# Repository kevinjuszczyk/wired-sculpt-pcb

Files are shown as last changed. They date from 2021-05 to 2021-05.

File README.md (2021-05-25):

# Design Files for Wired Sculpt Conversion Board
Modified for fabrication and assembly by JLCPCB.  
Components in the BOM with an LCSC number can be placed by JLCPCB.  
Remaining components can be ordered from Digikey and hand assembled.  
This design includes support for lighting the green LED and reading the media/Fn switch.

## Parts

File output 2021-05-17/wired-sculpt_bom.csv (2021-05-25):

Comment | Designator | Footprint | Desc | LCSC | Mfr | MfrPN | Link
10u | C2 | Capacitor_SMD:C_0603_1608Metric | 10uF ±10% 10V X5R | C19702 | Samsung Electro-Mechanics | CL10A106KP8NNNC
12p | C3,C4 | Capacitor_SMD:C_0603_1608Metric | 12pF ±5% 50V C0G 0603 | C38523 | Samsung Electro-Mechanics | CL10C120JB8NNNC
1u | C5 | Capacitor_SMD:C_0603_1608Metric | 1uF ±10% 50V X5R 0603 | C15849 | Samsung Electro-Mechanics | CL10A105KB8NNNC
100n | C6,C7,C8,C1 | Capacitor_SMD:C_0603_1608Metric | 100nF ±10% 50V X7R 0603 | C14663 | YAGEO | CC0603KRX7R9BB104
22u | C9,C10,C11 | Capacitor_SMD:C_0603_1608Metric | 22uF ±20% 6.3V X5R 0603 | C59461 | Samsung Electro-Mechanics | CL10A226MQ8NRNC
BAV99 | D1 | Package_TO_SOT_SMD:SOT-23 | Switching Diode 100V 125mA 1.25V @ 150mA 4ns SOT-23(SOT-23-3) | C2500 | Nexperia | BAV99,215
Red | D2 | LED_SMD:LED_0603_1608Metric_Castellated | Light Emitting Diodes (LED) Red 520~625nm 90~100mcd@20mA Top View 0603 | C2286 | Hubei KENTO Elec | KT-0603R
MountingHoleNorth | H1 | MountingHole:MountingHole_2.2mm_M2
MountingHoleSouth | H2 | MountingHole:MountingHole_2.2mm_M2
AlignmentHole | H3 | MountingHole:MountingHole_2.7mm
10103594-0001LF | J1 | Connector_USB:USB_Micro-B_Molex-105017-0001 | CONN RCPT USB2.0 MICRO B SMD R/A |  | Molex | 1050170001 | https://www.digikey.com/en/products/detail/molex/1050170001/2350885
AVR-ISP-6 - NOT FITTED | J2 | Connector_IDC:IDC-Header_2x03_P2.54mm_Horizontal
FFC3B07-30-T | J3 | Connector_FFC-FPC:TE_3-84952-0_1x30-1MP_P1.0mm_Horizontal | CONN FPC BOTTOM 30POS 1.00MM R/A |  | TE Connectivity AMP Connectors | 3-84952-0 | https://www.digikey.com/en/products/detail/te-connectivity-amp-connectors/3-84952-0/2180597
100 | R1 | Resistor_SMD:R_0603_1608Metric | 100Ω ±1% 1/10W ±200ppm/°C 0603 | C22775 | UNI-ROYAL(Uniroyal Elec) | 0603WAF1000T5E
22 | R2,R3 | Resistor_SMD:R_0402_1005Metric | 22Ω ±1% 1/16W ±200ppm/℃ 0402 | C25092 | UNI-ROYAL(Uniroyal Elec) | 0402WGF220JTCE
470k | R4 | Resistor_SMD:R_0603_1608Metric | 470kΩ ±1% 0.1W ±100ppm/℃ 0603 | C23178 | UNI-ROYAL(Uniroyal Elec) | 0603WAF4703T5E
680 | R5,R6 | Resistor_SMD:R_0603_1608Metric | 680Ω ±1% 0.1W ±100ppm/℃ 0603 | C23228 | UNI-ROYAL(Uniroyal Elec) | 0603WAF6800T5E
MJTP1117 | SW1 | kmj_custom:SW_Tactile_SPST_Angled_MJTP1117 | SWITCH TACTILE SPST-NO 0.05A 12V |  | APEM Inc. | MJTP1117 | https://www.digikey.com/en/products/detail/apem-inc/MJTP1117/1795496
SRV05-4-P-T7 | U1 | Package_TO_SOT_SMD:SOT-23-6 | TVS SOT-23-6 | C85364 | ProTek Devices | SRV05-4-P-T7
AT90USB1286-AU | U2 | Package_QFP:TQFP-64_14x14mm_P0.8mm | TQFP-64 MCU | C619147 | Microchip Tech | AT90USB1286-AU
16M | Y1 | Crystal:Crystal_SMD_3225-4Pin_3.2x2.5mm | SMD Crystal Resonators 16MHz ±10ppm SMD-3225_4P | C13738 | Yangxing Tech | X322516MLB4SI

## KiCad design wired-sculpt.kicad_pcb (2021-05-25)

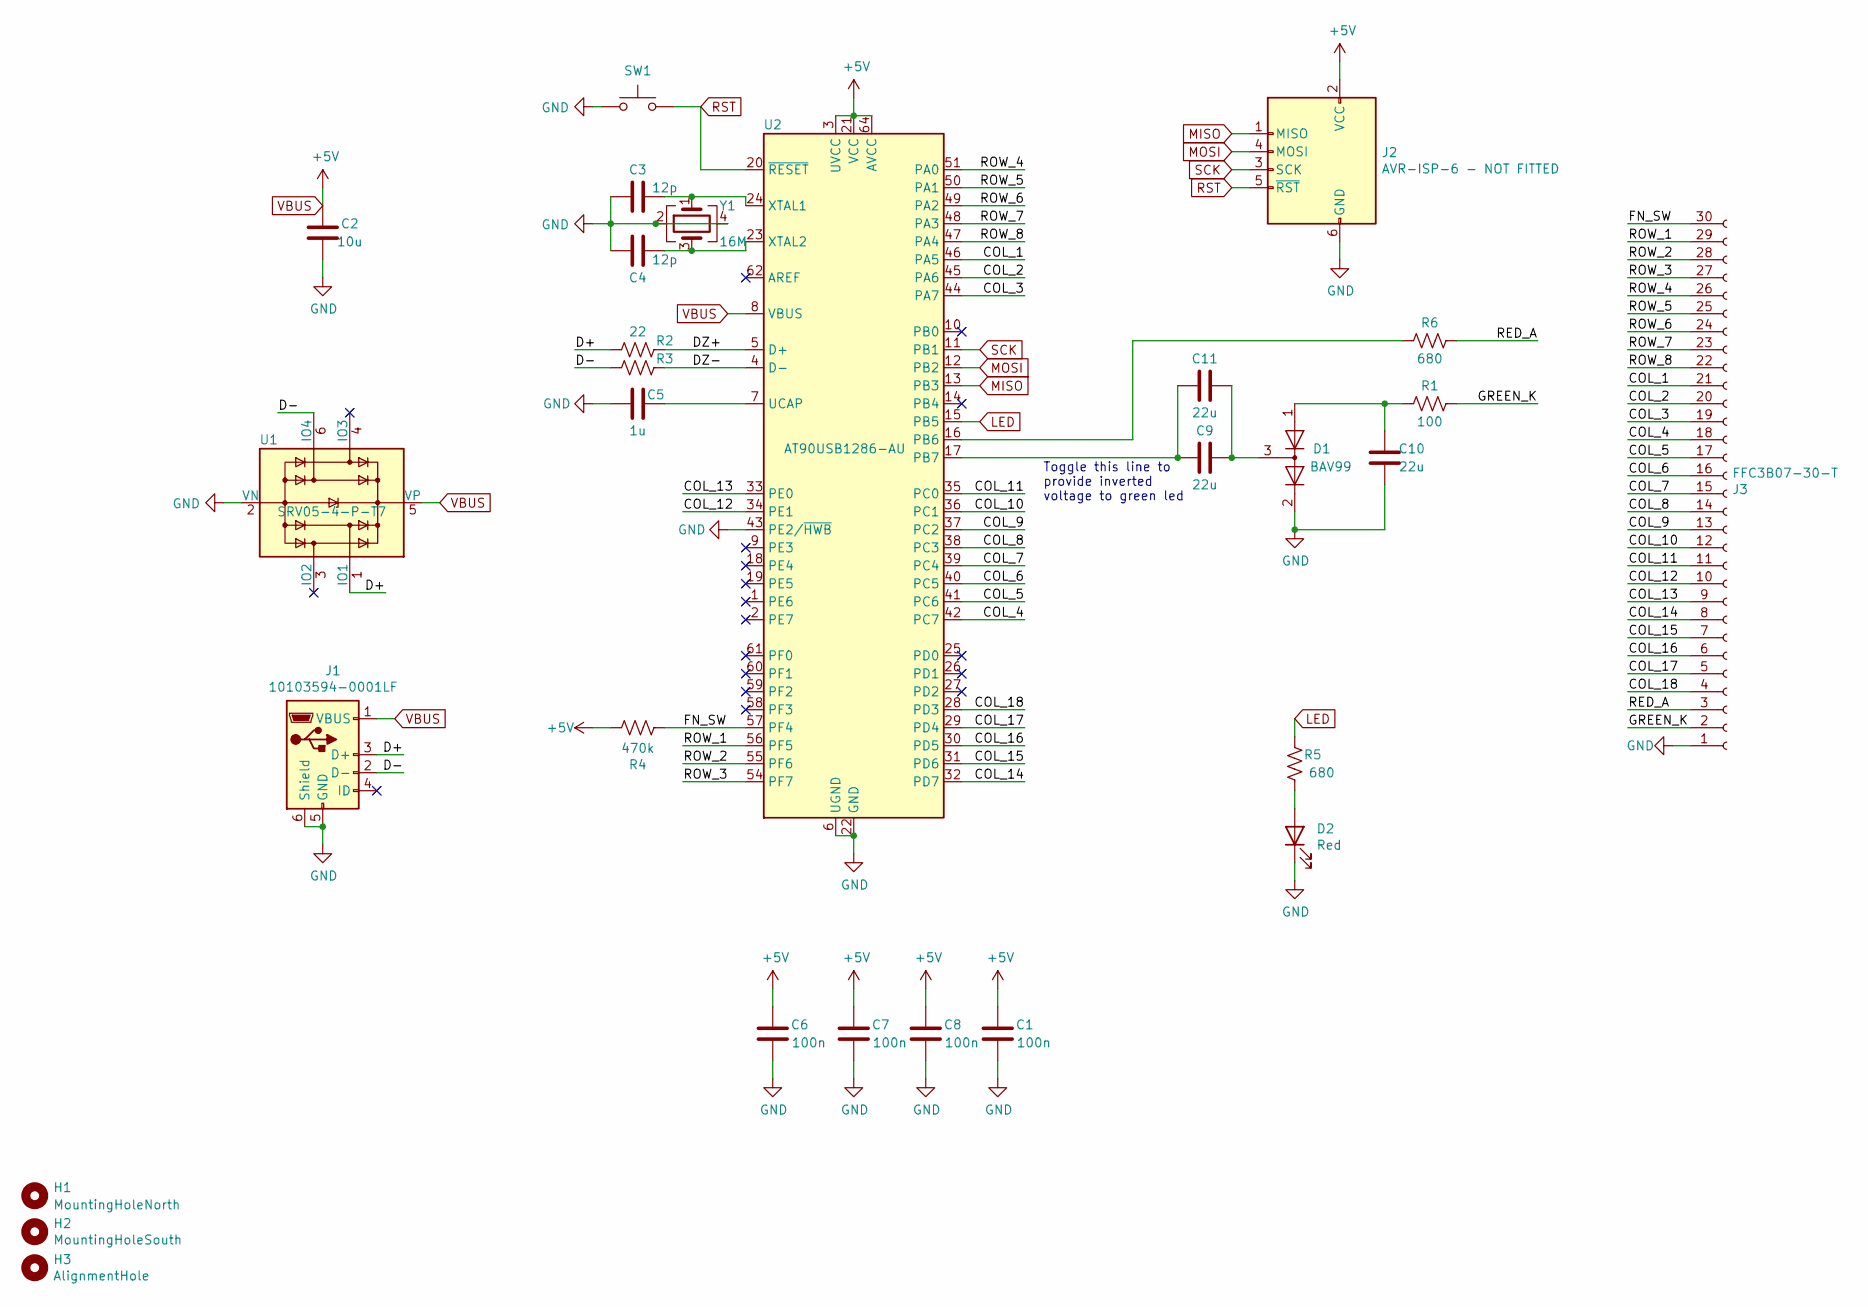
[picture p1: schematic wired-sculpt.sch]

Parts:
C1, C6, C7, C8: 100n; C_0603_1608Metric; Mfr_part CC0603KRX7R9BB104; LCSC C14663
C2: 10u; C_0603_1608Metric; Mfr_part CL10A106KP8NNNC; LCSC C19702
C3, C4: 12p; C_0603_1608Metric; Mfr_part CL10C120JB8NNNC; LCSC C38523
C5: 1u; C_0603_1608Metric; Mfr_part CL10A105KB8NNNC; LCSC C15849
C9, C10, C11: 22u; C_0603_1608Metric; Mfr_part CL10A226MQ8NRNC; LCSC C59461
D1: BAV99; SOT-23; Mfr_part BAV99,215; LCSC C2500
D2: Red; LED_0603_1608Metric_Castellated; Mfr_part KT-0603R; LCSC C2286
H1: MountingHoleNorth; MountingHole_2.2mm_M2
H2: MountingHoleSouth; MountingHole_2.2mm_M2
H3: AlignmentHole; MountingHole_2.7mm
J1: 10103594-0001LF; USB_Micro-B_Molex-105017-0001
J2: AVR-ISP-6 - NOT FITTED; IDC-Header_2x03_P2.54mm_Horizontal
J3: FFC3B07-30-T; TE_3-84952-0_1x30-1MP_P1.0mm_Horizontal
R1: 100; R_0603_1608Metric; Mfr_part 0603WAF1000T5E; LCSC C22775
R2, R3: 22; R_0402_1005Metric; Mfr_part 0402WGF220JTCE; LCSC C25092
R4: 470k; R_0603_1608Metric; Mfr_part 0603WAF4703T5E; LCSC C23178
R5, R6: 680; R_0603_1608Metric; Mfr_part 0603WAF6800T5E; LCSC C23228
SW1: MJTP1117; SW_Tactile_SPST_Angled_MJTP1117; Mfr_part MJTP1117
U1: SRV05-4-P-T7; SOT-23-6; Mfr_part SRV05-4-P-T7; LCSC C85364
U2: AT90USB1286-AU; TQFP-64_14x14mm_P0.8mm; Mfr_part AT90USB1286-AU; LCSC C619147
Y1: 16M; Crystal_SMD_3225-4Pin_3.2x2.5mm; Mfr_part X322516MLB4SI; LCSC C13738

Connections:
/COL_1: J3.21, U2.46 (PA5)
/COL_2: J3.20, U2.45 (PA6)
/COL_3: J3.19, U2.44 (PA7)
/COL_4: J3.18, U2.42 (PC7)
/COL_5: J3.17, U2.41 (PC6)
/COL_6: J3.16, U2.40 (PC5)
/COL_7: J3.15, U2.39 (PC4)
/COL_8: J3.14, U2.38 (PC3)
/COL_9: J3.13, U2.37 (PC2)
/COL_10: J3.12, U2.36 (PC1)
/COL_11: J3.11, U2.35 (PC0)
/COL_12: J3.10, U2.34 (PE1)
/COL_13: J3.9, U2.33 (PE0)
/COL_14: J3.8, U2.32 (PD7)
/COL_15: J3.7, U2.31 (PD6)
/COL_16: J3.6, U2.30 (PD5)
/COL_17: J3.5, U2.29 (PD4)
/COL_18: J3.4, U2.28 (PD3)
/D+: J1.3 (D+), R2.2, U1.1 (IO1)
/D-: J1.2 (D-), R3.2, U1.6 (IO4)
/DZ+: R2.1, U2.5 (D+)
/DZ-: R3.1, U2.4 (D-)
/FN_SW: J3.30, R4.2, U2.57 (PF4)
/GREEN_K: J3.2, R1.1
/RED_A: J3.3, R6.1
/ROW_1: J3.29, U2.56 (PF5)
/ROW_2: J3.28, U2.55 (PF6)
/ROW_3: J3.27, U2.54 (PF7)
/ROW_4: J3.26, U2.51 (PA0)
/ROW_5: J3.25, U2.50 (PA1)
/ROW_6: J3.24, U2.49 (PA2)
/ROW_7: J3.23, U2.48 (PA3)
/ROW_8: J3.22, U2.47 (PA4)
GND: C1.1, C2.1, C3.2, C4.2, C5.2, C6.1, C7.1, C8.1, C10.1, D1.2 (A), D2.1 (K), J1.5 (GND), J1.6 (Shield), J2.6 (GND), J3.1, SW1.1, U1.2 (VN), U2.6 (UGND), U2.22 (GND), U2.43 (PE2/~HWB), U2.53 (GND), U2.63 (GND), Y1.2, Y1.4
LED: R5.2, U2.15 (PB5)
MISO: J2.1 (MISO), U2.13 (PB3)
MOSI: J2.4 (MOSI), U2.12 (PB2)
unnamed: C3.1, U2.24 (XTAL1), Y1.1
unnamed: C4.1, U2.23 (XTAL2), Y1.3
unnamed: C5.1, U2.7 (UCAP)
unnamed: C10.2, D1.1 (K), R1.2
unnamed: C9.1, C11.1, D1.3 (K)
unnamed: C9.2, C11.2, U2.17 (PB7)
unnamed: D2.2 (A), R5.1
unnamed: R6.2, U2.16 (PB6)
RST: J2.5 (~RST), SW1.2, U2.20 (~RESET)
SCK: J2.3 (SCK), U2.11 (PB1)
VBUS: C1.2, C2.2, C6.2, C7.2, C8.2, J1.1 (VBUS), J2.2 (VCC), R4.1, U1.5 (VP), U2.3 (UVCC), U2.8 (VBUS), U2.21 (VCC), U2.52 (VCC), U2.64 (AVCC)

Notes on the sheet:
Toggle this line to provide inverted voltage to green led

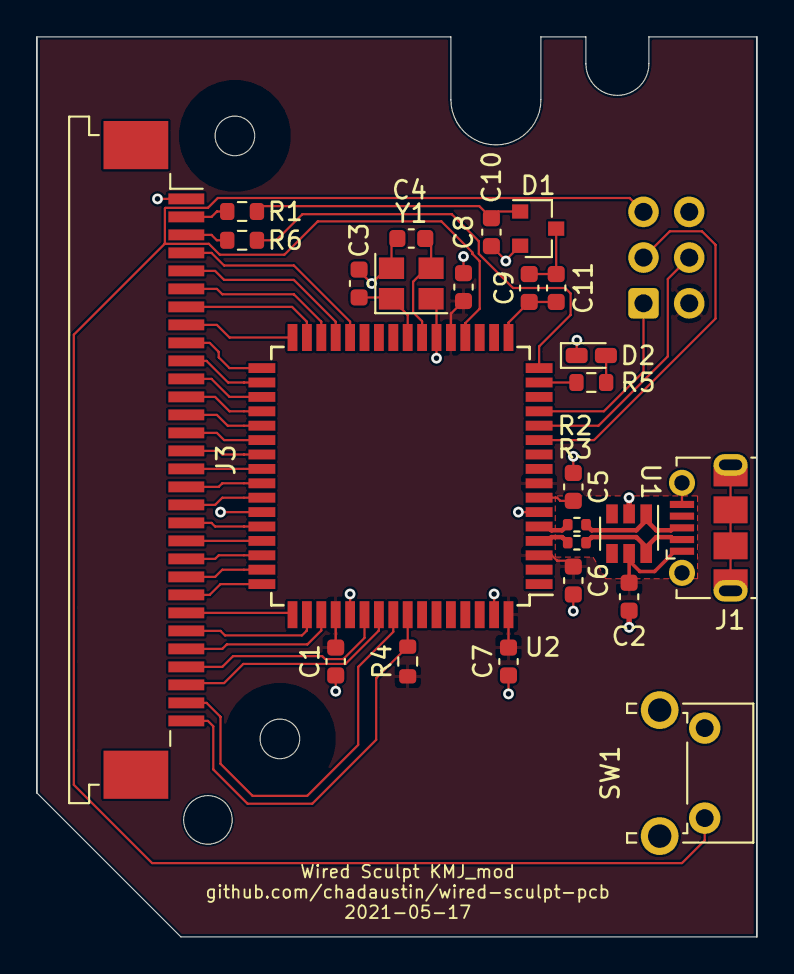
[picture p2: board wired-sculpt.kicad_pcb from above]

Board: 2 copper layers, 40.0 x 50.0 mm, 29 parts (1 on the bottom side), 48 nets.
